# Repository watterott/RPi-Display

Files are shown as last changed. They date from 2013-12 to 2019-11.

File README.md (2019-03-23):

# RPi-Display
2.8" TFT-Display (320x240) with Touchpanel for all Raspberry Pi Models.

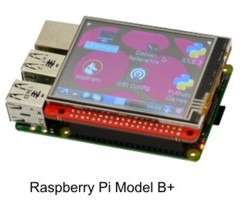
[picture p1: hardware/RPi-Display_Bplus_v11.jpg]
RPi-Display B+

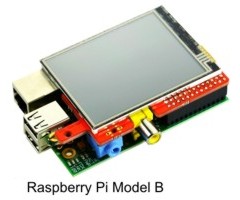
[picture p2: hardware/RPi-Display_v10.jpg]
RPi-Display


* Open-Source and released under the [Creative Commons Attribution Share-Alike License](https://creativecommons.org/licenses/by-sa/4.0/).
* **[Documentation on learn.watterott.com](https://learn.watterott.com)**

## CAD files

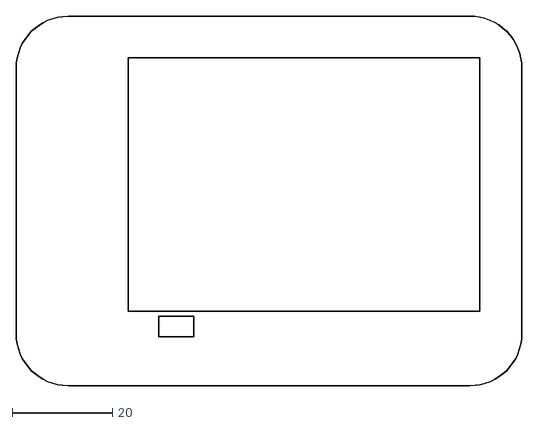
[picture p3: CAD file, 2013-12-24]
hardware/TEK-BERRY.dxf
100.7 x 73.6

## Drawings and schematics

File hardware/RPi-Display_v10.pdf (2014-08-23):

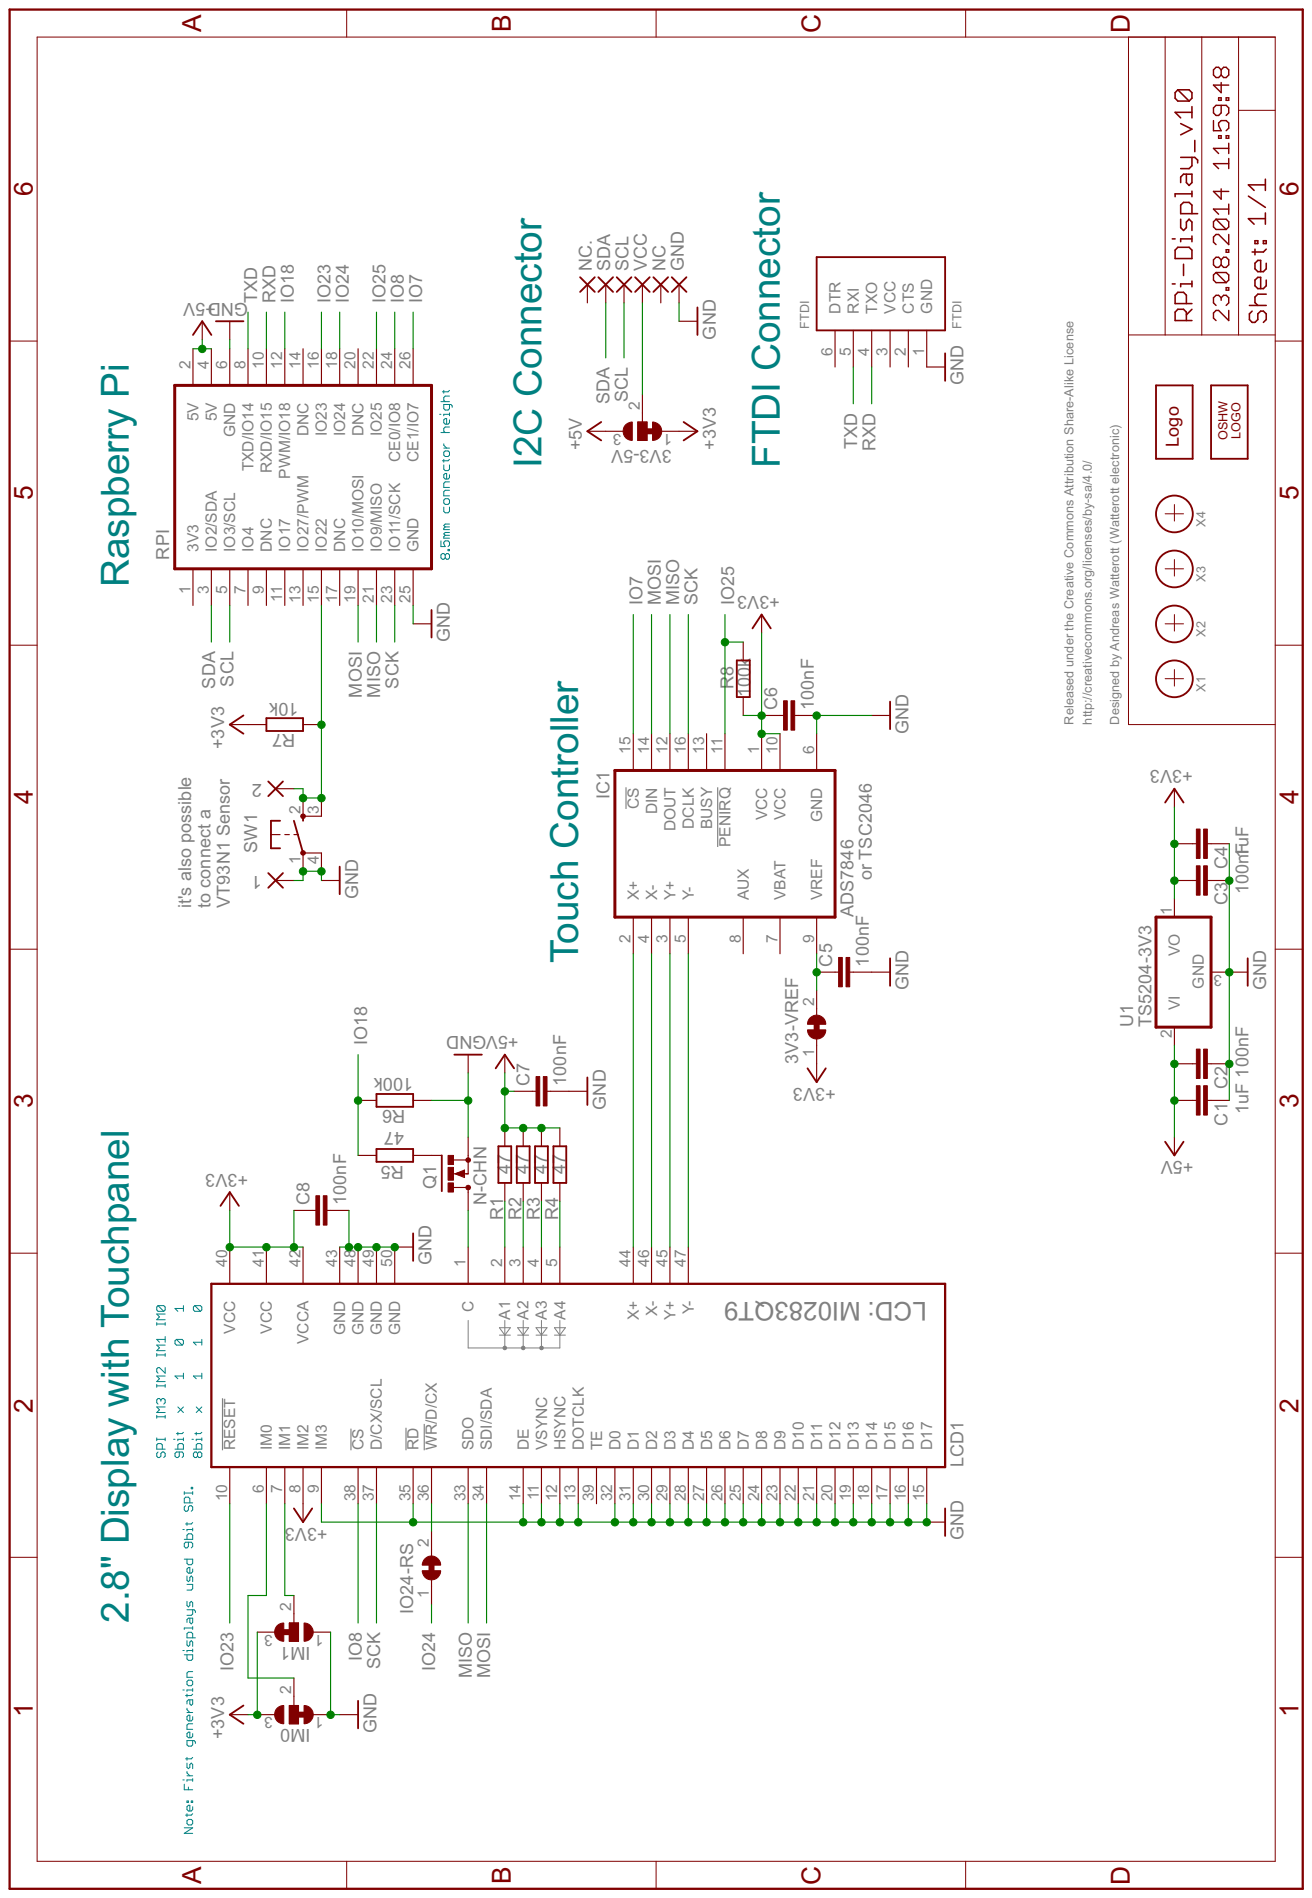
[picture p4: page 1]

GND DNG GND 100nF 100nF TS5204-3V3 1uF 47474747 N-CHN DNG 3V3+ GND 74 100nF GND k001 13V3+ 00nF GND GND GND 3V3+ 3V3+ 3V3+ +3V3 GND k01 +3V3 1uF 100nF 100nF GNDV5+ V5+ 100k V5+ GND GND +3V3 +5V Released under the Creative Commons Attribution Share-Alike License http://creativecommons.org/licenses/by-sa/4.0/ Designed by Andreas Watterott (Watterott electronic) or TSC2046 it's also possible to connect a VT93N1 Sensor RPI 3V3 1 IO2/SDA 3 IO3/SCL 5 5V 2 5V 4 GND 6 IO4 7 DNC 9 TXD/IO14 8 RXD/IO15 10 IO17 11 IO27/PWM 13 IO22 15 PWM/IO18 12 DNC 14 IO23 16 DNC 17 IO10/MOSI 19 IO24 18 DNC 20 IO9/MISO 21 IO11/SCK 23 GND 25 IO25 22 CE0/IO8 24 CE1/IO7 26 C2 C3 GND VI 2 3 VO 1 U1 C1 X1 X2 X3 X4 9TQ3820I M: DCL LCD1 VCC 40 GND 43 VCC 41 X+ 44 SDO 33 RESET 10 D5 27 D4 28 D3 29 D2 30 D1 31 D0 32 RD 35 WR/D/CX 36 D/CX/SCL 37 SDI/SDA 34 A1 2 C 1 A2 3 A3 4 A4 5 VCCA 42 IM0 6 IM1 7 IM2 8 IM3 9 VSYNC 11 HSYNC 12 DOTCLK 13 DE 14 D6 26 D7 25 D8 24 D9 23 D10 22 D11 21 D12 20 D13 19 D14 18 D15 17 D16 16 D17 15 CS 38 TE 39 X- 46 Y+ 45 Y- 47 GND 48 GND 49 GND 50 R1R2R3R4 Q15R X+ 2 Y+ 3 Y- 5 AUX 8 DCLK 16 CS 15 DIN 14 BUSY 13 DOUT 12 PENIRQ 11 X- 4 GND 6 VCC 1 VBAT 7 VCC 10 VREF 9 IC1 ADS7846 C5 6R 2 13V3-VREF C7 2 1 IO24-RS 3 1 2 0 MI 3 1 2 1 MI 7R C4 C8 C6R8 NC. SDA SCL VCC NCGND FTDI FTDI DTR 6 RXI 5 TXO 4 VCC 3 CTS 2 GND 1 SW1 1 23 4 21 3 1 2 V5- 3V3 SDA SDA SCL SCL MISO MISO MISO MOSI MOSI MOSI SCK SCK SCK IO23 IO23 IO24 IO24 IO25 IO25 IO8 IO8 IO7 IO7 IO18 IO18 TXD TXD RXD RXD Logo OSHW LOGO ABCD 1 2 3 4 5 6 ABCD 1 2 3 4 5 6 2.8" Display with Touchpanel Raspberry Pi Touch Controller I2C Connector FTDI Connector

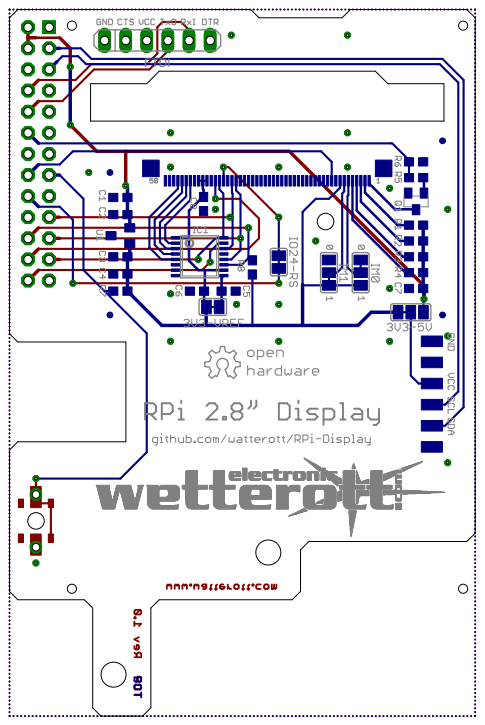
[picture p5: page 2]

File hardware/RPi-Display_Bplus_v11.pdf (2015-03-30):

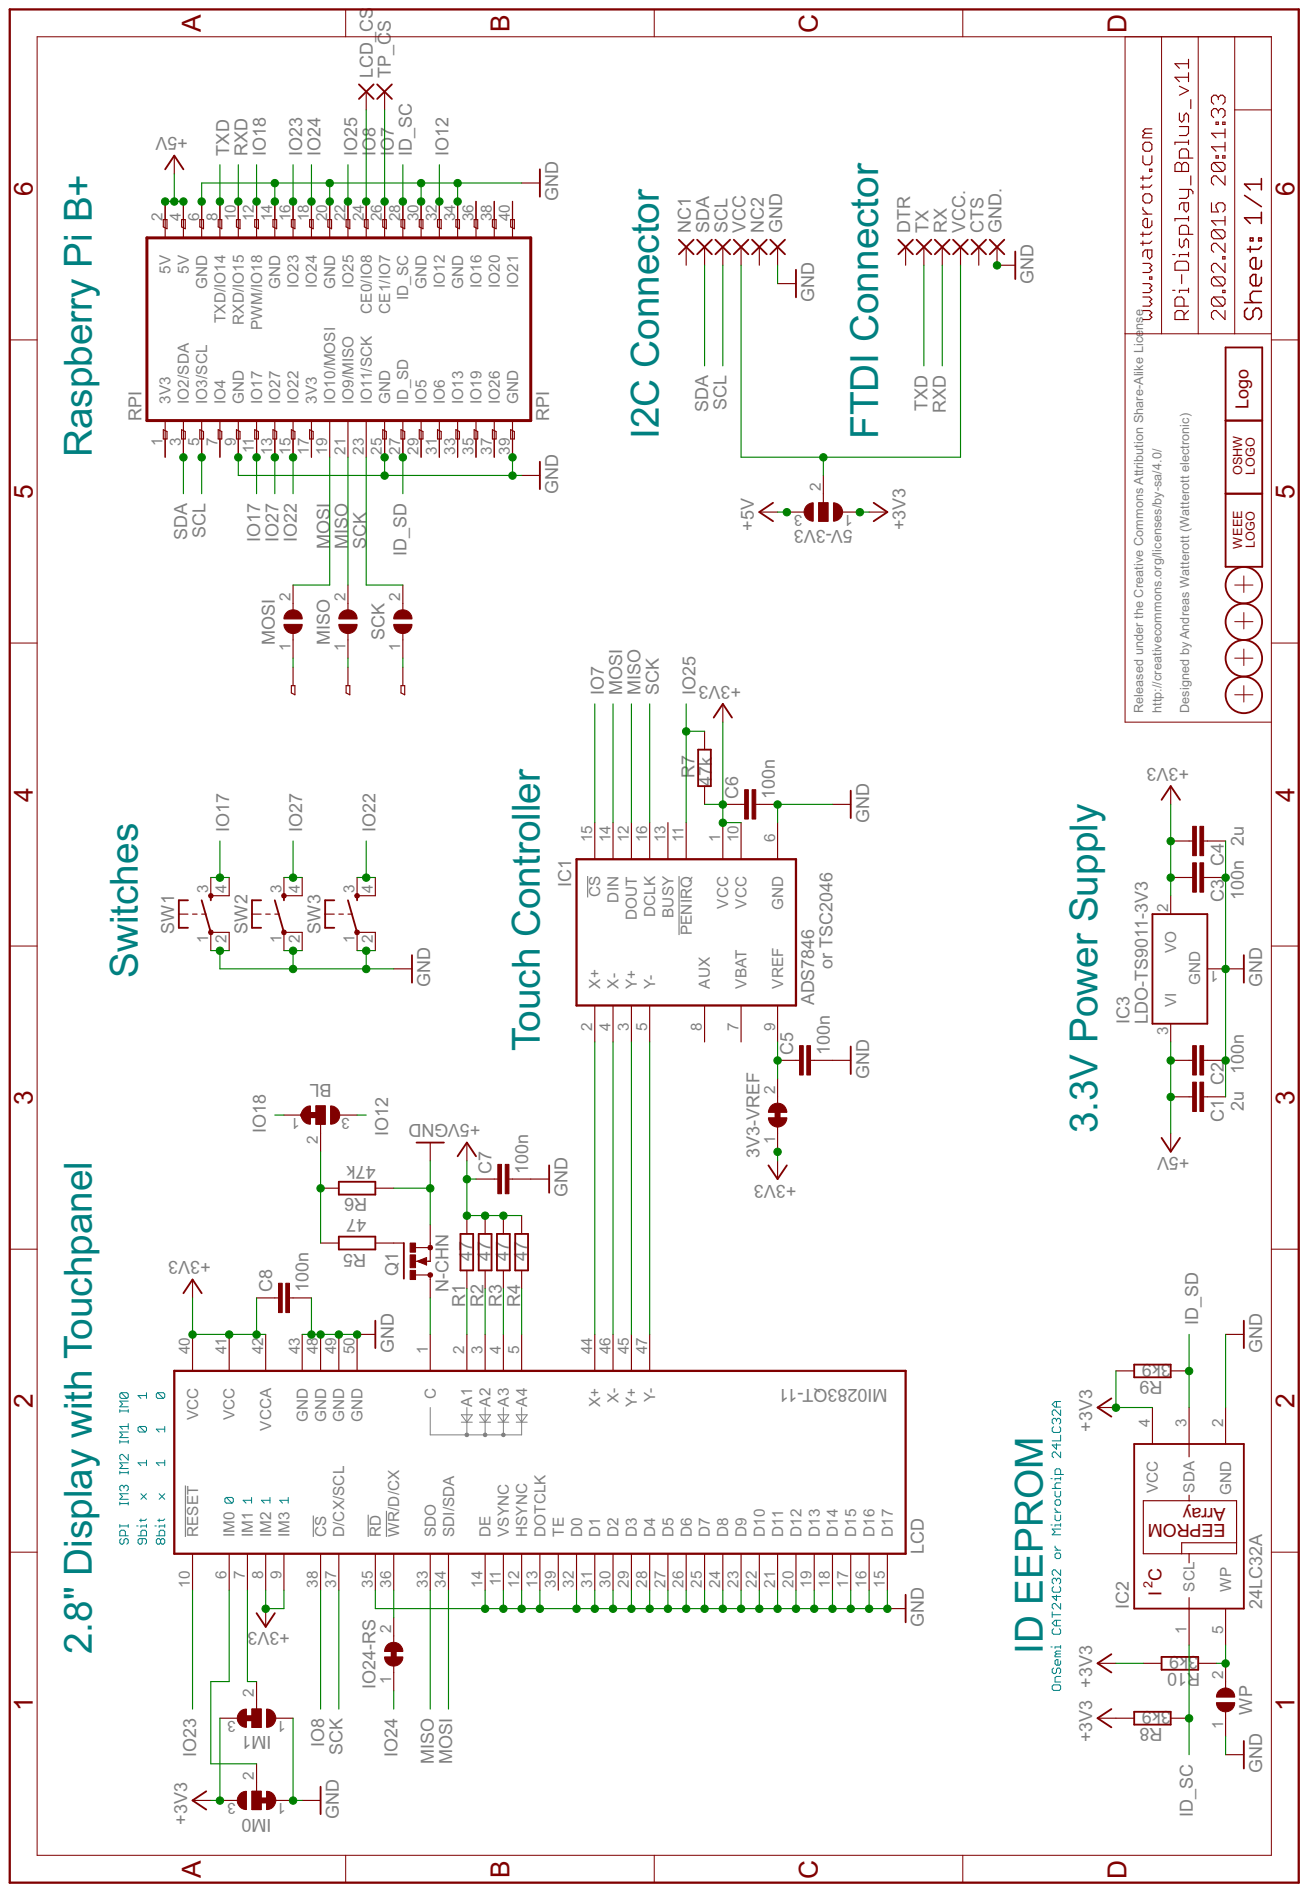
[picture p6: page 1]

LDO-TS9011-3V3 Released under the Creative Commons Attribution Share-Alike License

http://creativecommons.org/licenses/by-sa/4.0/ Designed by Andreas Watterott (Watterott electronic)

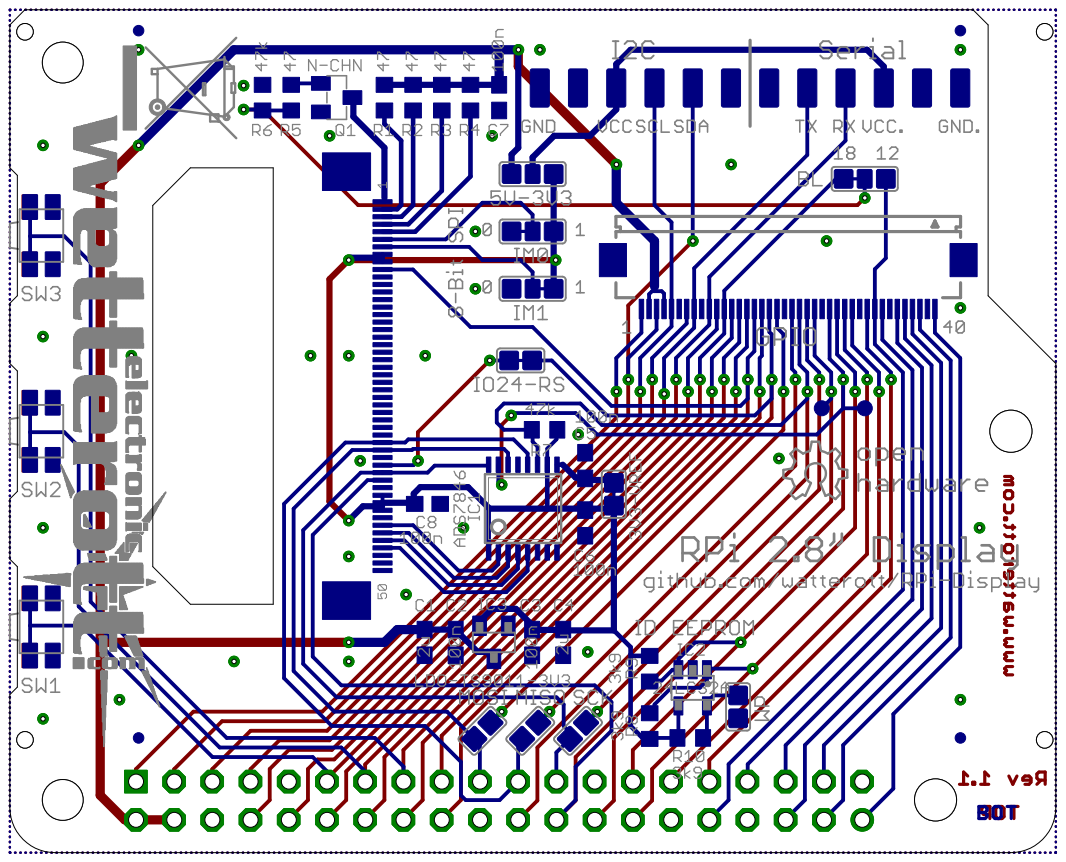
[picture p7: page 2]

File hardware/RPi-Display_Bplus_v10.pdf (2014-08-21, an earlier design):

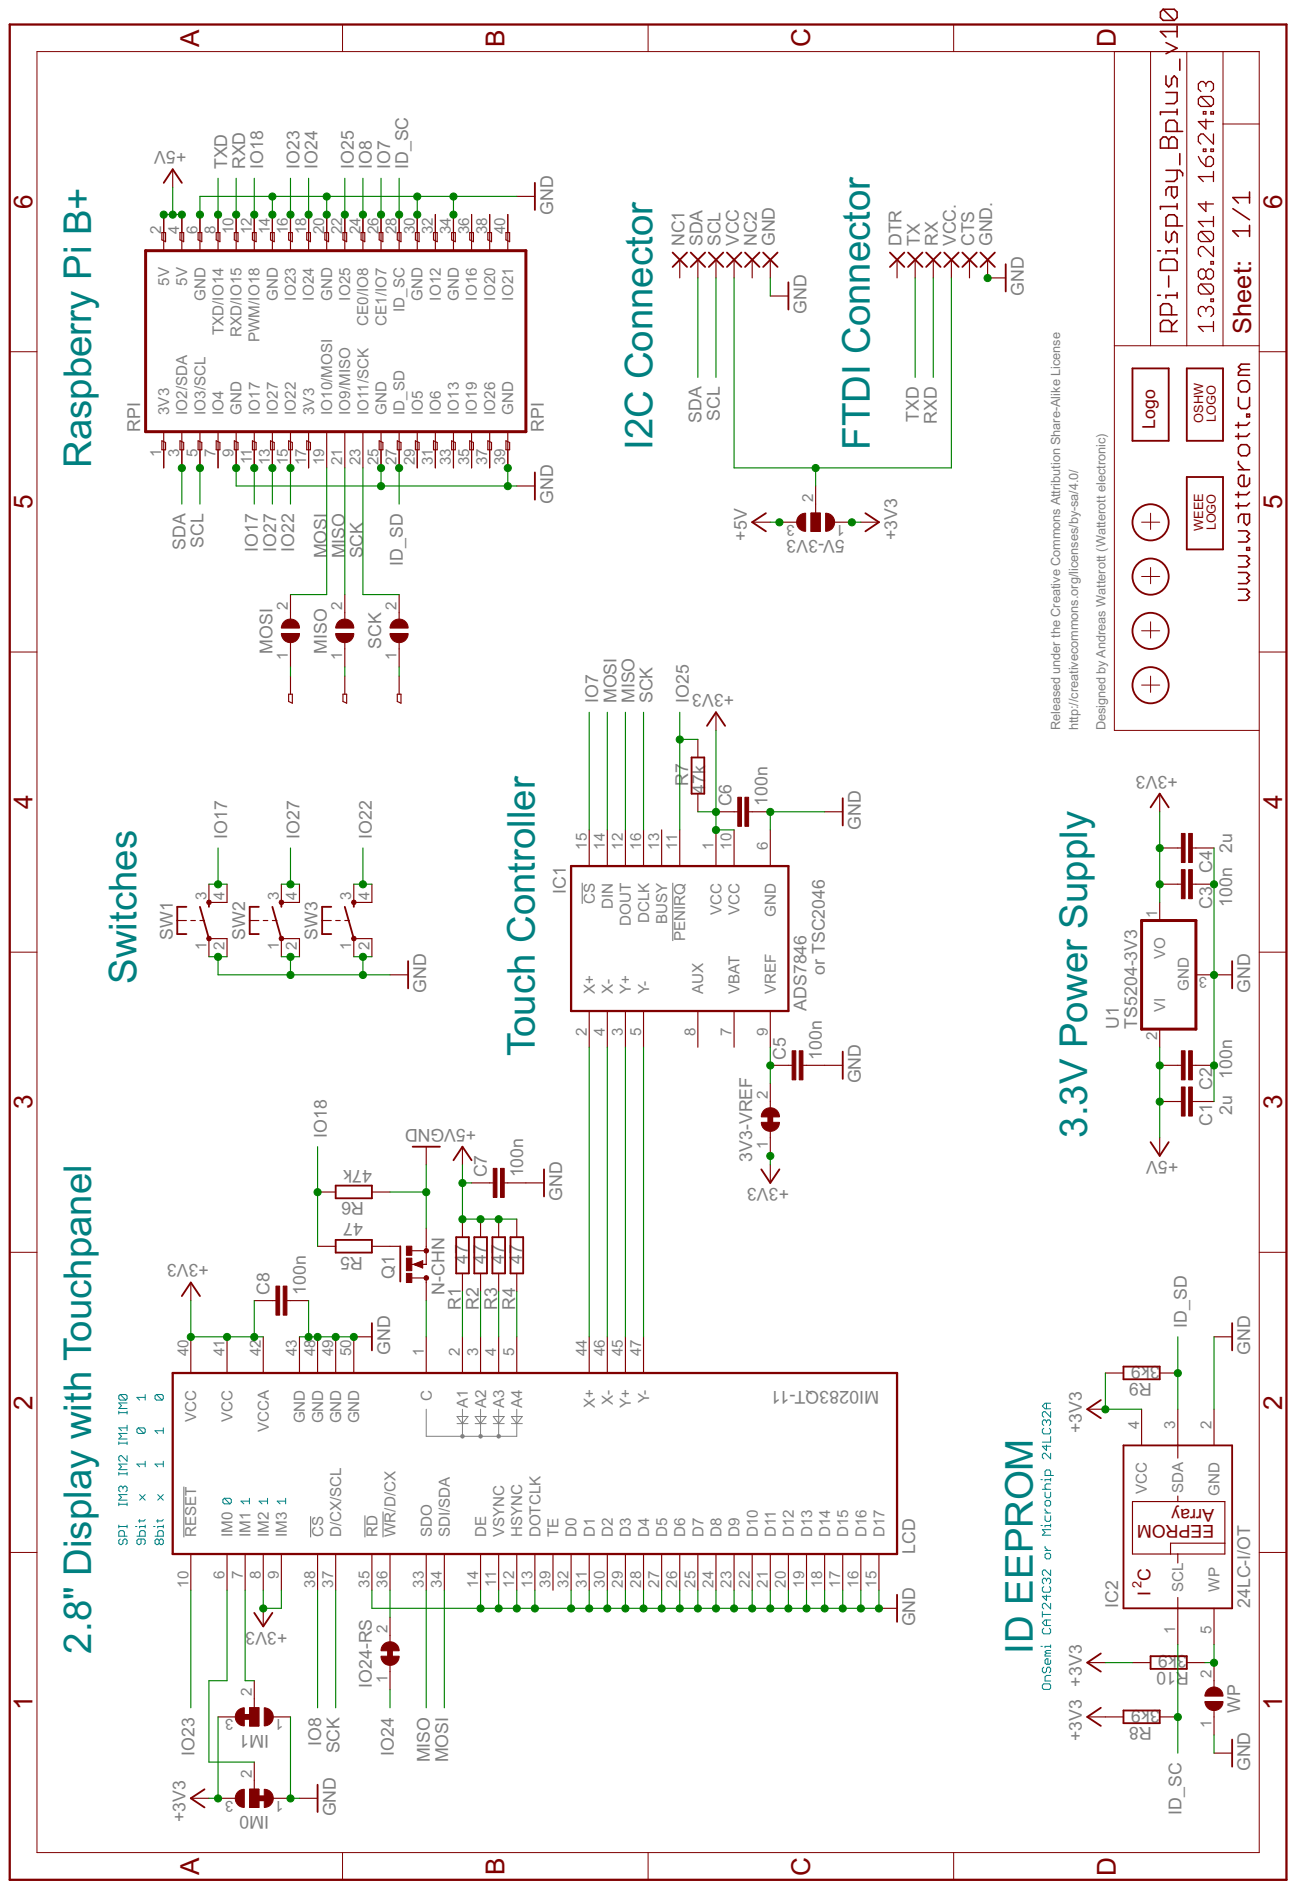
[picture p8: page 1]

Released under the Creative Commons Attribution Share-Alike License

http://creativecommons.org/licenses/by-sa/4.0/ Designed by Andreas Watterott (Watterott electronic)

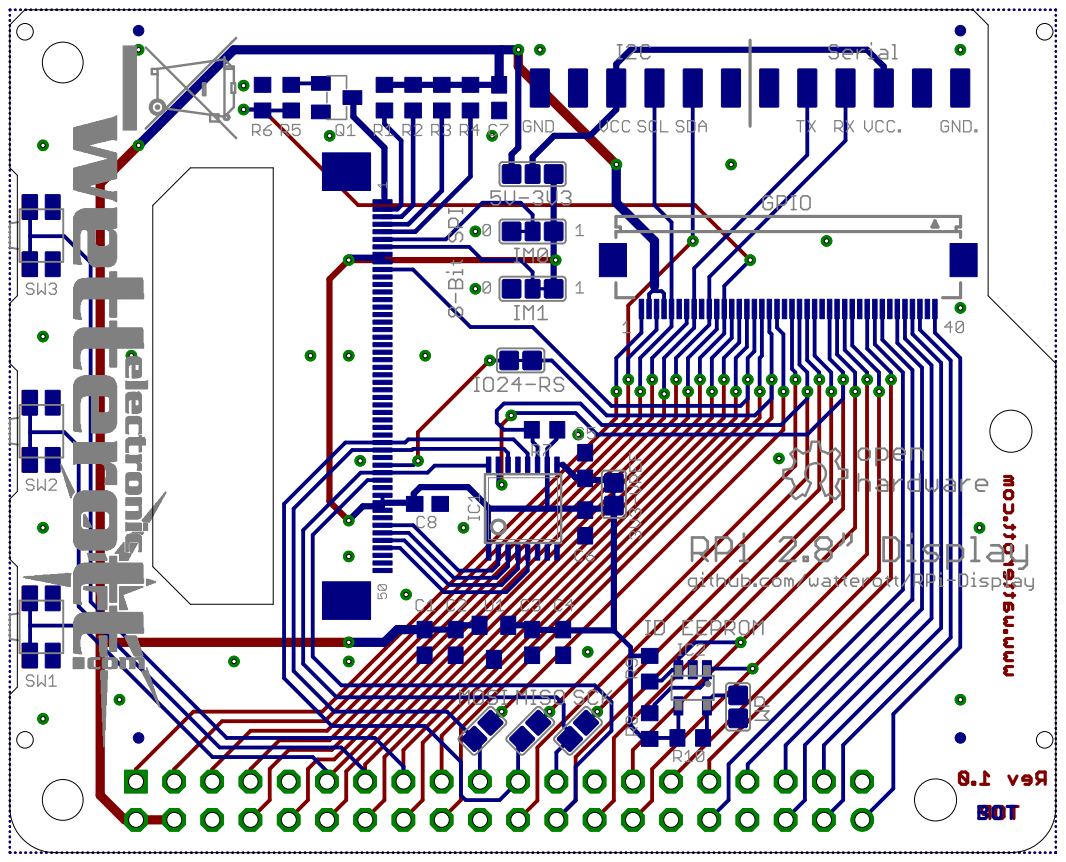
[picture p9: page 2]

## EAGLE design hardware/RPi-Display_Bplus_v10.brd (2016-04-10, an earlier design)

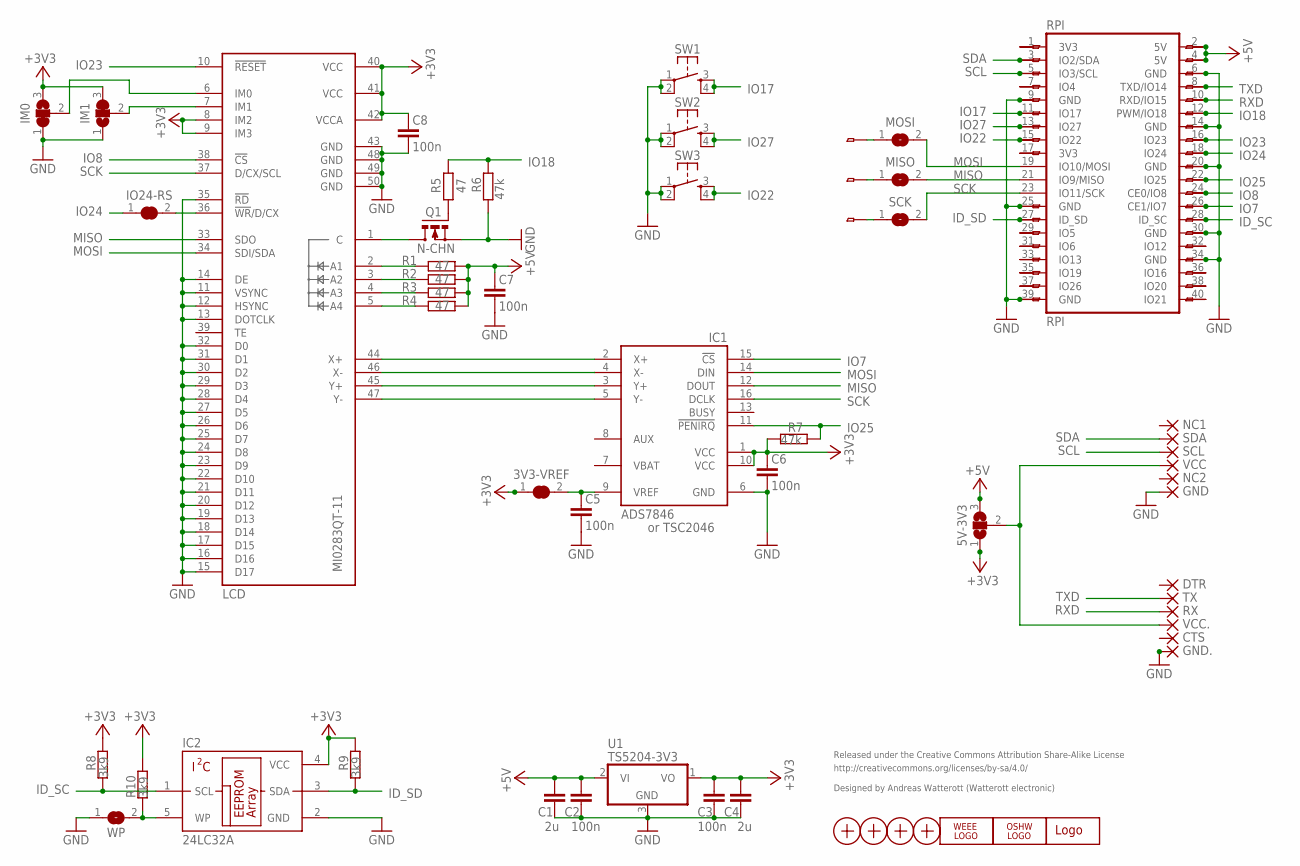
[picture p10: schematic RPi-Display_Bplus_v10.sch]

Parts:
3V3-VREF: JUMPER2-NOCREAM; JUMPER2_NC
5V-3V3: JUMPER3-NOCREAM; JUMPER3_NC
C1, C4: 2u; C0603
C2, C3, C5, C6, C7, C8: 100n; C0603
CTS: PAD-1.27-NC; PAD-1.27X2.54_NC
DTR: PAD-1.27-NC; PAD-1.27X2.54_NC
GND, GND.: PAD-1.27-NC; PAD-1.27X2.54_NC
GPIO: FH12-40S-0.5SH
IC1: ADS7846; SSOP16
IC2: 24LC32A; SOT23-5
IM0, IM1: JUMPER3-NOCREAM; JUMPER3_NC
IO24-RS: JUMPER2-NOCREAM; JUMPER2_NC
LCD: MI0283QT-11; MI0283QT11
LOGO1: OSHW_LOGO_6MILX0150-NT; OSHW_6X150_NOTEXT
LOGO2: WEEE_LOGO; WEEE
MISO: JUMPER2-NOCREAM; JUMPER2_NC
MOSI: JUMPER2-NOCREAM; JUMPER2_NC
NC1, NC2: PAD-1.27-NC; PAD-1.27X2.54_NC
Q1: N-CHN; MICRO3
R1, R2, R3, R4, R5: 47; R0603
R6, R7: 47k; R0603
R8, R9, R10: 3k9; R0603
RPI: RPI; RPI_B+
RX: PAD-1.27-NC; PAD-1.27X2.54_NC
SCK: JUMPER2-NOCREAM; JUMPER2_NC
SCL: PAD-1.27-NC; PAD-1.27X2.54_NC
SDA: PAD-1.27-NC; PAD-1.27X2.54_NC
SW1, SW2, SW3: SWITCH-PTS840P; SW_PTS840P
TX: PAD-1.27-NC; PAD-1.27X2.54_NC
U1: TS5204-3V3; SOT23
U$1: WE-LOGO
VCC, VCC.: PAD-1.27-NC; PAD-1.27X2.54_NC
WP: JUMPER2-NOCREAM; JUMPER2_NC
X1, X2, X3, X4: PASSER

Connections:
+3V3: 3V3-VREF.1, 5V-3V3.1, C3.1, C4.1, C6.1, C8.1, IC1.1 (VCC), IC1.10 (VCC), IC2.4 (VCC), IM0.3, IM1.3, LCD.8 (IM2), LCD.9 (IM3), LCD.40 (VCC), LCD.41 (VCC), LCD.42 (VCCA), R7.2, R8.1, R9.1, R10.1, U1.1 (VO)
+5V: 5V-3V3.3, C1.1, C2.1, C7.1, GPIO.37, GPIO.39, R1.2, R2.2, R3.2, R4.2, RPI.2 (5V), RPI.4 (5V), U1.2 (VI)
C1: LCD.1 (C), Q1.3 (D)
GND: C1.2, C2.2, C3.2, C4.2, C5.2, C6.2, C7.2, C8.2, GND.1, GND..1, GPIO.2, GPIO.7, GPIO.11, GPIO.16, GPIO.21, GPIO.27, GPIO.32, GPIO.35, IC1.6 (GND), IC2.2 (GND), IM0.1, IM1.1, LCD.11 (VSYNC), LCD.12 (HSYNC), LCD.13 (DOTCLK), LCD.14 (DE), LCD.15 (D17), LCD.16 (D16), LCD.17 (D15), LCD.18 (D14), LCD.19 (D13), LCD.20 (D12), LCD.21 (D11), LCD.22 (D10), LCD.23 (D9), LCD.24 (D8), LCD.25 (D7), LCD.26 (D6), LCD.27 (D5), LCD.28 (D4), LCD.29 (D3), LCD.30 (D2), LCD.31 (D1), LCD.32 (D0), LCD.35 (!RD), LCD.43 (GND), LCD.48 (GND), LCD.49 (GND), LCD.50 (GND), Q1.2 (S), R6.2, RPI.6 (GND), RPI.9 (GND), RPI.14 (GND), RPI.20 (GND), RPI.25 (GND), RPI.30 (GND), RPI.34 (GND), RPI.39 (GND), SW1.1, SW1.2 (P1), SW2.1, SW2.2 (P1), SW3.1, SW3.2 (P1), U1.3 (GND), WP.1
ID_SC: GPIO.13, IC2.1 (SCL), R8.2, RPI.28 (ID_SC)
ID_SD: GPIO.14, IC2.3 (SDA), R9.2, RPI.27 (ID_SD)
IM0: IM0.2, LCD.6 (IM0)
IM1: IM1.2, LCD.7 (IM1)
IO7: GPIO.15, IC1.15 (!CS), RPI.26 (CE1/IO7)
IO8: GPIO.17, LCD.38 (!CS), RPI.24 (CE0/IO8)
IO17: GPIO.30, RPI.11 (IO17), SW1.3 (S), SW1.4 (S1)
IO18: GPIO.29, R5.2, R6.1, RPI.12 (PWM/IO18)
IO22: GPIO.26, RPI.15 (IO22), SW3.3 (S), SW3.4 (S1)
IO23: GPIO.25, LCD.10 (!RESET), RPI.16 (IO23)
IO24: GPIO.23, IO24-RS.1, RPI.18 (IO24)
IO25: GPIO.19, IC1.11 (!PENIRQ), R7.1, RPI.22 (IO25)
IO27: GPIO.28, RPI.13 (IO27), SW2.3 (S), SW2.4 (S1)
LEDPWM: Q1.1 (G), R5.1
LED_A1: LCD.2 (A1), R1.1
LED_A2: LCD.3 (A2), R2.1
LED_A3: LCD.4 (A3), R3.1
LED_A4: LCD.5 (A4), R4.1
MISO: IC1.12 (DOUT), LCD.33 (SDO), MISO.2, RPI.21 (IO9/MISO)
MOSI: IC1.14 (DIN), LCD.34 (SDI/SDA), MOSI.2, RPI.19 (IO10/MOSI)
unnamed: IO24-RS.2, LCD.36 (!WR!/D/CX)
unnamed: IC2.5 (WP), R10.2, WP.2
unnamed: GPIO.22, MOSI.1
unnamed: 5V-3V3.2, VCC.1, VCC..1
unnamed: GPIO.20, MISO.1
unnamed: GPIO.18, SCK.1
unnamed: GPIO.40, RPI.1 (3V3)
unnamed: GPIO.34, RPI.7 (IO4)
unnamed: GPIO.24, RPI.17 (3V3)
unnamed: GPIO.12, RPI.29 (IO5)
unnamed: GPIO.10, RPI.31 (IO6)
unnamed: GPIO.8, RPI.33 (IO13)
unnamed: GPIO.6, RPI.35 (IO19)
unnamed: GPIO.4, RPI.37 (IO26)
unnamed: GPIO.9, RPI.32 (IO12)
unnamed: GPIO.5, RPI.36 (IO16)
unnamed: GPIO.3, RPI.38 (IO20)
unnamed: GPIO.1, RPI.40 (IO21)
RXD: GPIO.31, RPI.10 (RXD/IO15), RX.1
SCK: IC1.16 (DCLK), LCD.37 (D/CX/SCL), RPI.23 (IO11/SCK), SCK.2
SCL: GPIO.36, RPI.5 (IO3/SCL), SCL.1
SDA: GPIO.38, RPI.3 (IO2/SDA), SDA.1
TXD: GPIO.33, RPI.8 (TXD/IO14), TX.1
VREF: 3V3-VREF.2, C5.1, IC1.9 (VREF)
X+: IC1.2 (X+), LCD.44 (X+)
X-: IC1.4 (X-), LCD.46 (X-)
Y+: IC1.3 (Y+), LCD.45 (Y+)
Y-: IC1.5 (Y-), LCD.47 (Y-)

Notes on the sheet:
Released under the Creative Commons Attribution Share-Alike License
http://creativecommons.org/licenses/by-sa/4.0/
Designed by Andreas Watterott (Watterott electronic)
or TSC2046

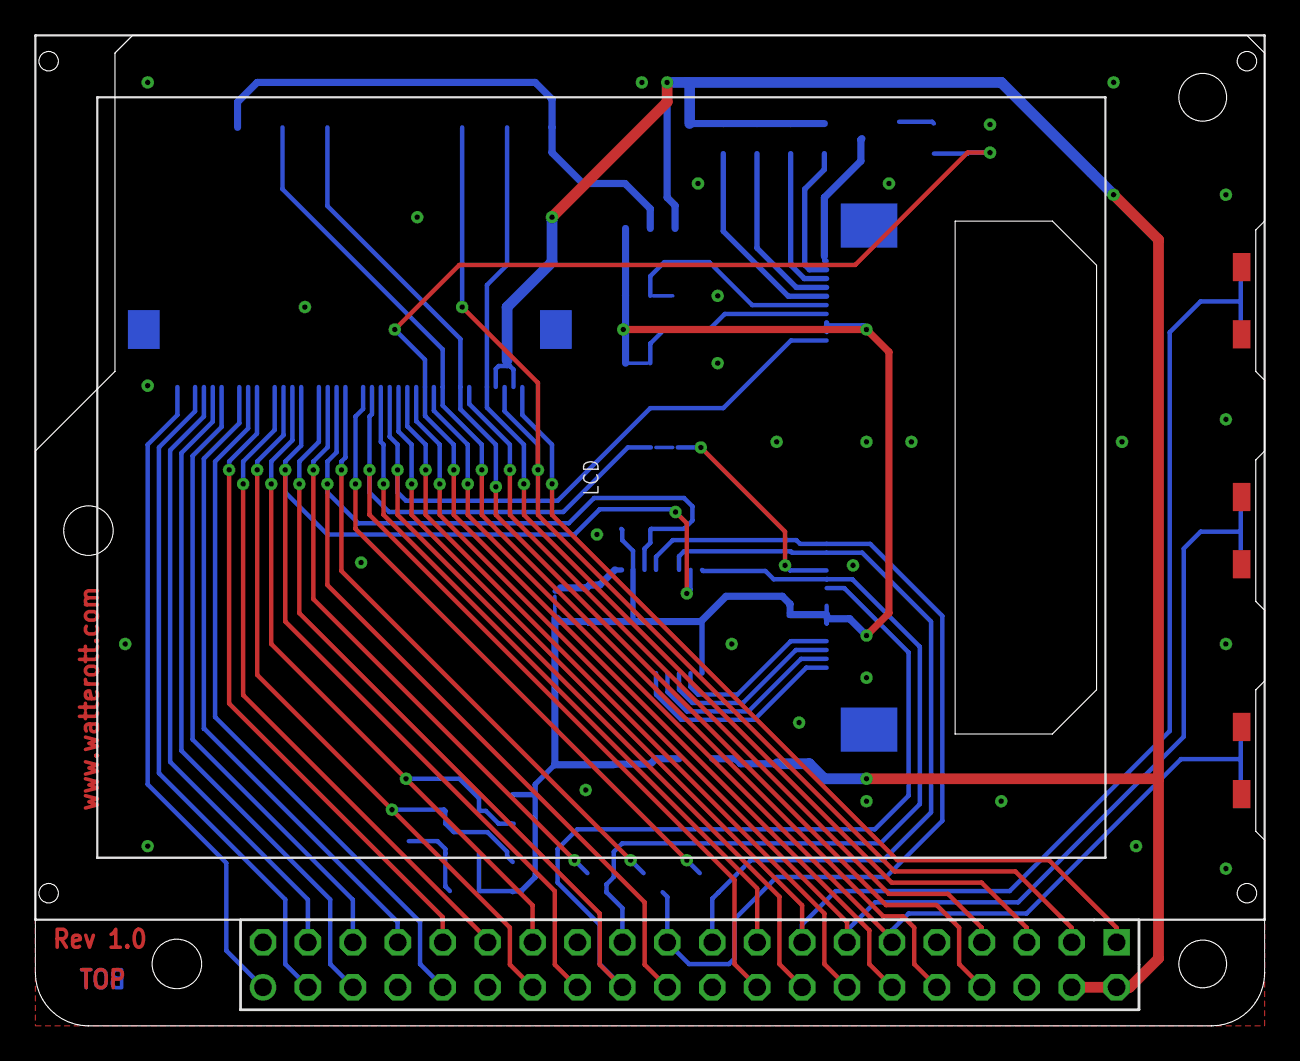
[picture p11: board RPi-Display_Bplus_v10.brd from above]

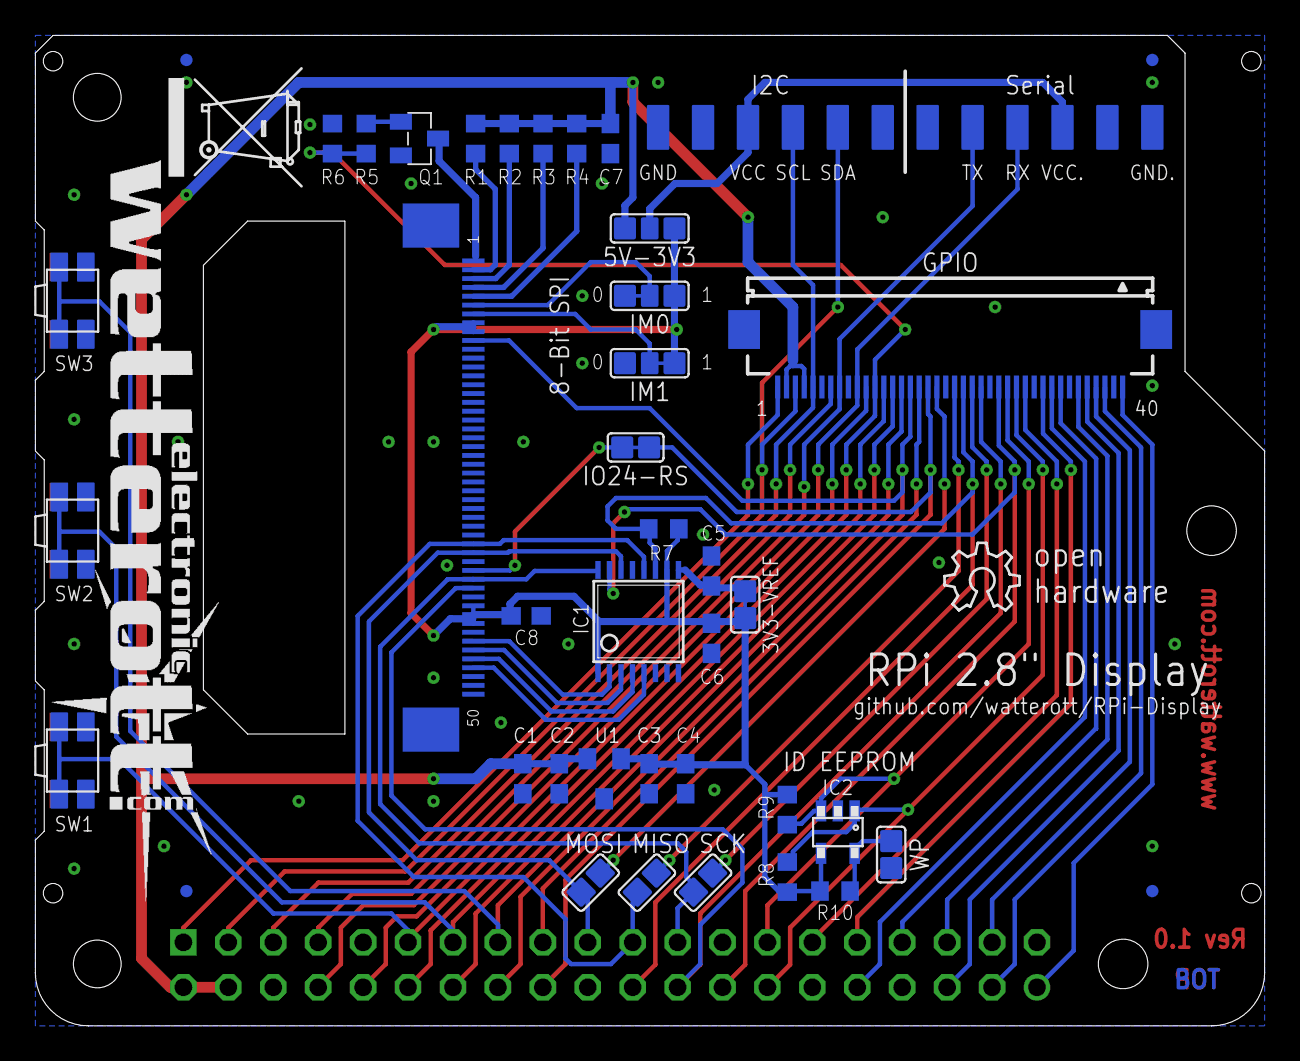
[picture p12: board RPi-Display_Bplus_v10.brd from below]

Board: 2 copper layers, 69.5 x 56.0 mm, 56 parts (54 on the bottom side), 52 nets.

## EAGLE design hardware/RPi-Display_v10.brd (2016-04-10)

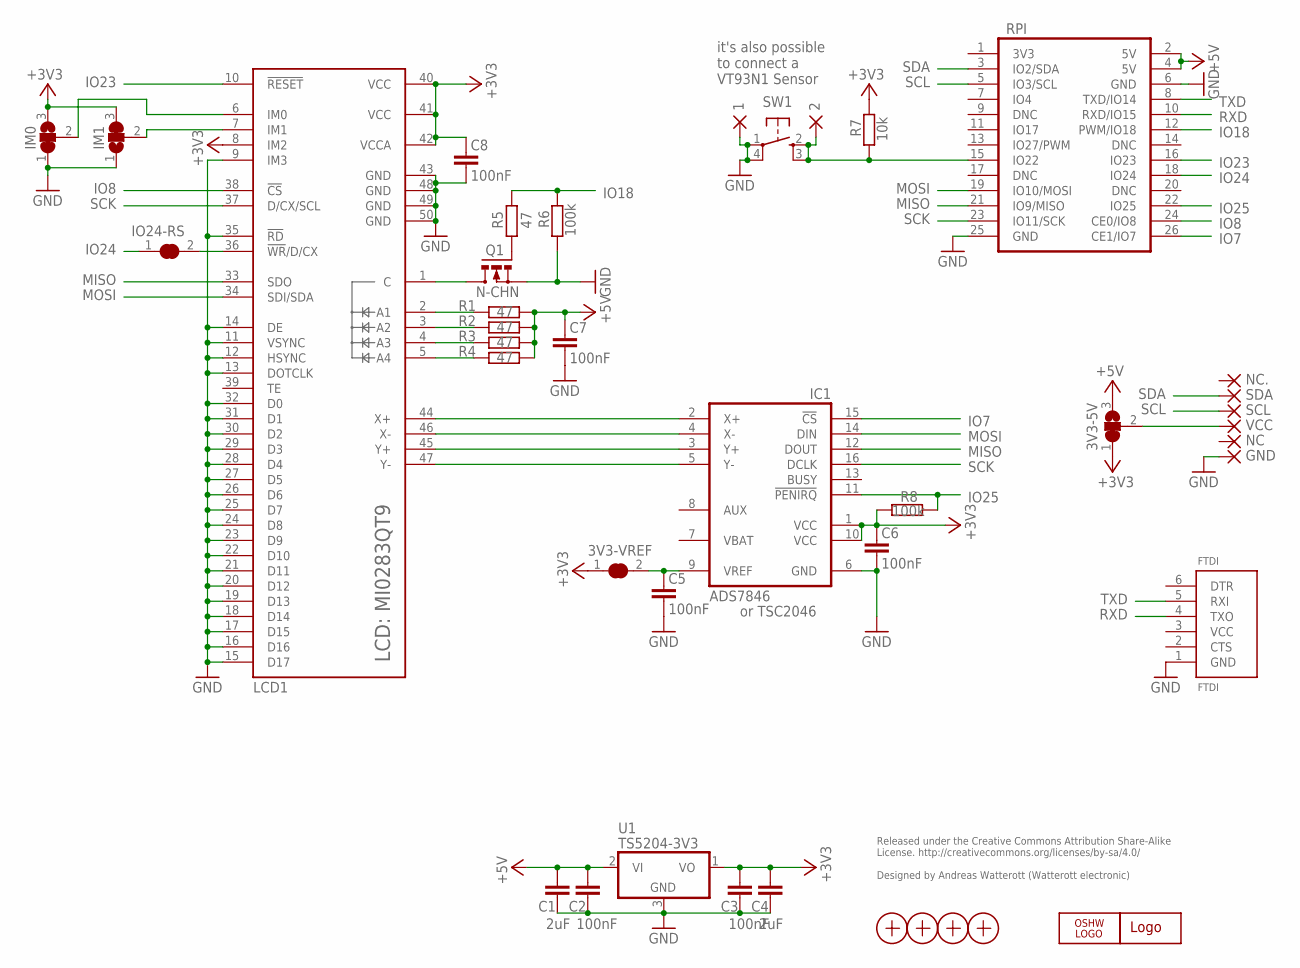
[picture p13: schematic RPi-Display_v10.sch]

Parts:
1, 2: WIREPADSMD1,27-254; SMD1,27-2,54
3V3-5V: SJ2W; SJ_2
3V3-VREF: SJ
C1, C4: 2uF; C0603
C2, C3, C5, C6, C7, C8: 100nF; C0603
FTDI: FTDI
GND: WIREPADSMD1,27-254; SMD1,27-2,54
IC1: ADS7846; SSOP16
IM0, IM1: SJ2W; SJ_2
IO24-RS: SJ
LCD1: MI0283QT9
LOGO1: OSHW_LOGO_6MILX0150-NT; OSHW_6X150_NOTEXT
NC, NC.: WIREPADSMD1,27-254; SMD1,27-2,54
Q1: N-CHN; MICRO3
R1, R2, R3, R4, R5: 47; R0603
R6, R8: 100k; R0603
R7: 10k; R0603
RPI: RPI
SCL: WIREPADSMD1,27-254; SMD1,27-2,54
SDA: WIREPADSMD1,27-254; SMD1,27-2,54
SW1: SW4S; SW_SMD4
U1: TS5204-3V3; SOT23
U$1: WE-LOGO
VCC: WIREPADSMD1,27-254; SMD1,27-2,54
X1, X2, X3, X4: PASSER

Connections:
+3V3: 3V3-5V.1, 3V3-VREF.1, C3.1, C4.1, C6.1, C8.1, IC1.1 (VCC), IC1.10 (VCC), IM0.3, IM1.3, LCD1.8 (IM2), LCD1.40 (VCC), LCD1.41 (VCC), LCD1.42 (VCCA), R7.1, R8.2, U1.1 (VO)
+5V: 3V3-5V.3, C1.1, C2.1, C7.1, R1.2, R2.2, R3.2, R4.2, RPI.2 (5V), RPI.4 (5V), U1.2 (VI)
C1: LCD1.1 (C), Q1.3 (D)
GND: 1.1, C1.2, C2.2, C3.2, C4.2, C5.2, C6.2, C7.2, C8.2, FTDI.1 (GND), GND.1, IC1.6 (GND), IM0.1, IM1.1, LCD1.9 (IM3), LCD1.11 (VSYNC), LCD1.12 (HSYNC), LCD1.13 (DOTCLK), LCD1.14 (DE), LCD1.15 (D17), LCD1.16 (D16), LCD1.17 (D15), LCD1.18 (D14), LCD1.19 (D13), LCD1.20 (D12), LCD1.21 (D11), LCD1.22 (D10), LCD1.23 (D9), LCD1.24 (D8), LCD1.25 (D7), LCD1.26 (D6), LCD1.27 (D5), LCD1.28 (D4), LCD1.29 (D3), LCD1.30 (D2), LCD1.31 (D1), LCD1.32 (D0), LCD1.35 (!RD), LCD1.43 (GND), LCD1.48 (GND), LCD1.49 (GND), LCD1.50 (GND), Q1.2 (S), R6.2, RPI.6 (GND), RPI.25 (GND), SW1.1, SW1.4 (P1), U1.3 (GND)
IM0: IM0.2, LCD1.6 (IM0)
IM1: IM1.2, LCD1.7 (IM1)
IO7: IC1.15 (!CS), RPI.26 (CE1/IO7)
IO8: LCD1.38 (!CS), RPI.24 (CE0/IO8)
IO18: R5.2, R6.1, RPI.12 (PWM/IO18)
IO22: 2.1, R7.2, RPI.15 (IO22), SW1.2 (S), SW1.3 (S1)
IO23: LCD1.10 (!RESET), RPI.16 (IO23)
IO24: IO24-RS.1, RPI.18 (IO24)
IO25: IC1.11 (!PENIRQ), R8.1, RPI.22 (IO25)
LEDPWM: Q1.1 (G), R5.1
LED_A1: LCD1.2 (A1), R1.1
LED_A2: LCD1.3 (A2), R2.1
LED_A3: LCD1.4 (A3), R3.1
LED_A4: LCD1.5 (A4), R4.1
MISO: IC1.12 (DOUT), LCD1.33 (SDO), RPI.21 (IO9/MISO)
MOSI: IC1.14 (DIN), LCD1.34 (SDI/SDA), RPI.19 (IO10/MOSI)
unnamed: IO24-RS.2, LCD1.36 (!WR!/D/CX)
unnamed: 3V3-5V.2, VCC.1
RXD: FTDI.4 (TXO), RPI.10 (RXD/IO15)
SCK: IC1.16 (DCLK), LCD1.37 (D/CX/SCL), RPI.23 (IO11/SCK)
SCL: RPI.5 (IO3/SCL), SCL.1
SDA: RPI.3 (IO2/SDA), SDA.1
TXD: FTDI.5 (RXI), RPI.8 (TXD/IO14)
VREF: 3V3-VREF.2, C5.1, IC1.9 (VREF)
X+: IC1.2 (X+), LCD1.44 (X+)
X-: IC1.4 (X-), LCD1.46 (X-)
Y+: IC1.3 (Y+), LCD1.45 (Y+)
Y-: IC1.5 (Y-), LCD1.47 (Y-)

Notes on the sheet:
Released under the Creative Commons Attribution Share-Alike License. http://creativecommons.org/licenses/by-sa/4.0/ Designed by Andreas Watterott (Watterott electronic)
or TSC2046
it's also possible to connect a VT93N1 Sensor

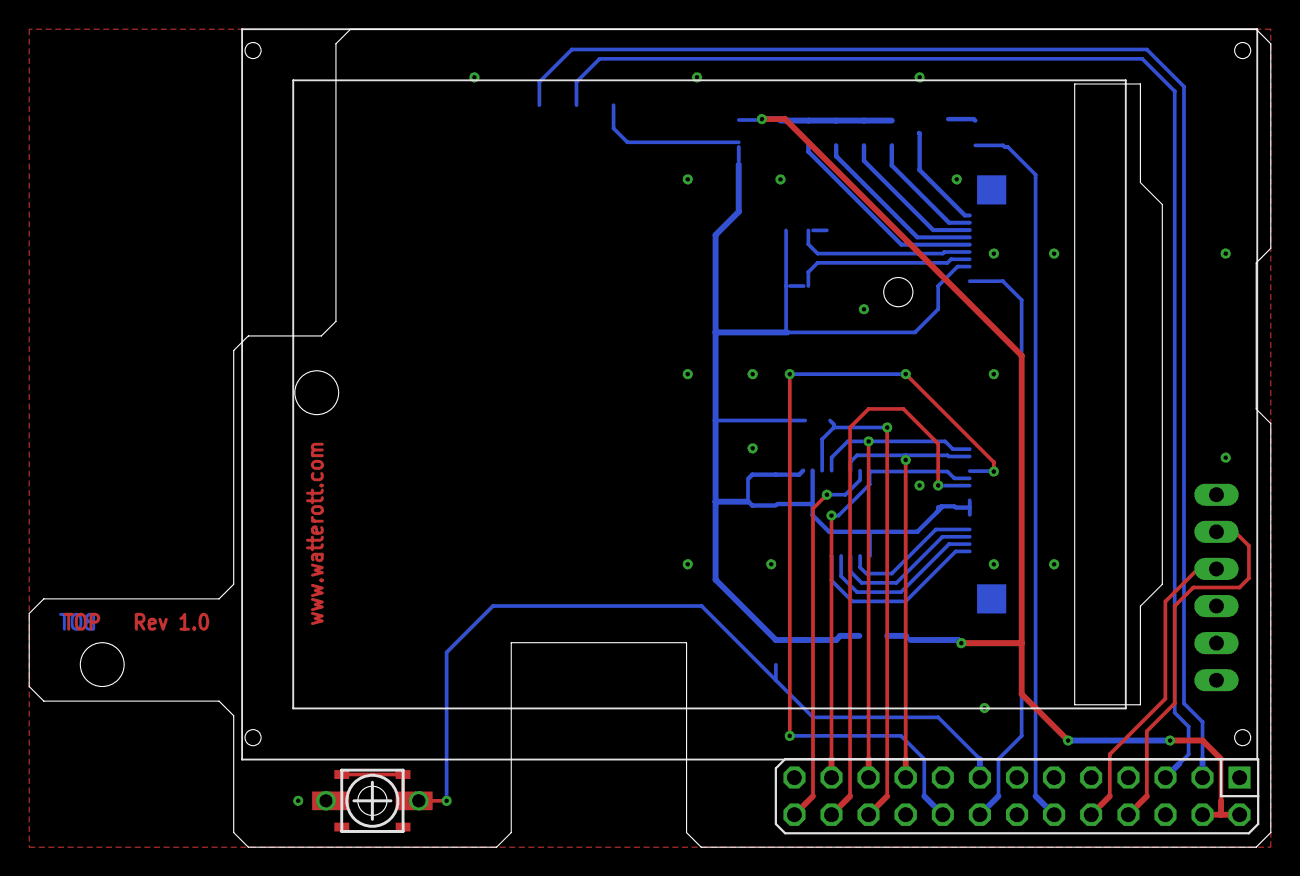
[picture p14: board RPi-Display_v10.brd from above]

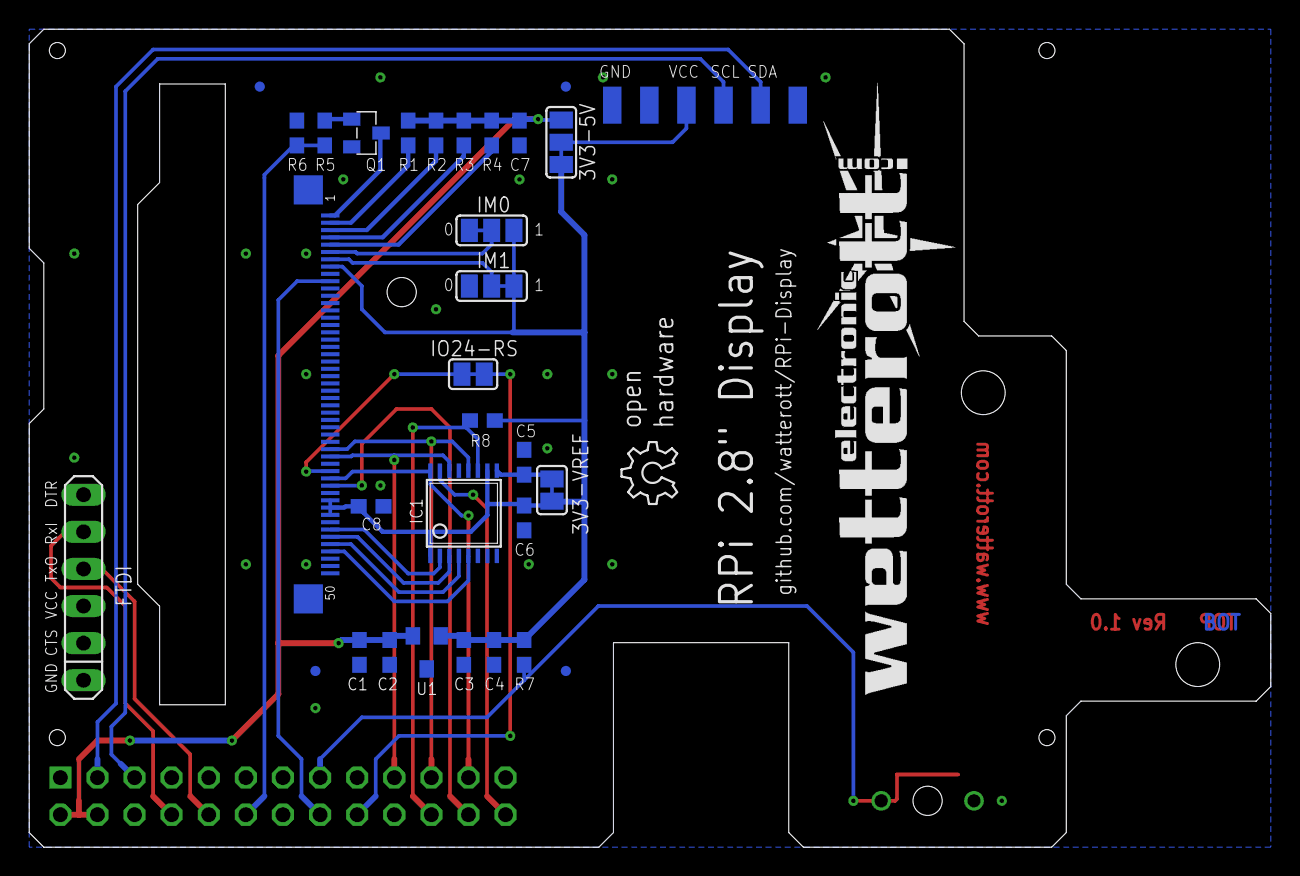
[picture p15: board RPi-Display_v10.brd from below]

Board: 2 copper layers, 85.0 x 56.0 mm, 42 parts (37 on the bottom side), 32 nets.

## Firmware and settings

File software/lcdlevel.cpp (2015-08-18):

//============================================================================
// Name        : lcdlevel.cpp
// Author      : Friedemann Wolpert
// Version     : 1.0.0
// Copyright   : All Rights Reversed, based on wiringPi / Pi-blaster
// Description : Backlight control for Watterott RPi Display (Soft PWM Pin 18)
// Building :
//   * Install WiringPi: http://wiringpi.com/download-and-install/
//   * Compile: cc -o lcdlevel lcdlevel.cpp -lwiringPi -lpthread
//   * Set execution right: chmod +x lcdlevel
//============================================================================

//#include <iostream>
#include <stdio.h>
#include <stdlib.h>
#include <sys/types.h>
#include <sys/stat.h>
#include <getopt.h>
#include <unistd.h>

using namespace std;

#include "wiringPi.h"
#include "softPwm.h"

#define DEVFILE "/dev/lcdlevel"
//#define DEVFILE "/home/pi/lcd"

static char VERSION[] = "1.0.0";
static int lcdlevel = 100;

static void parseDevFileLoop(void);


void parseargs(int argc, char **argv)
{
  int index=0;
  int c;

  static struct option longopts[] =
  {
    {"help", no_argument, 0, 'h'},
    {"level", required_argument, 0, 'l'},
    {"version", no_argument, 0, 'v'},
    {0, 0, 0, 0}
  };

  while((c = getopt_long(argc, argv, "hl:v", longopts, &index )) != -1)
  {
    switch(c)
    {
      case 0:
        break;

      case 'h':
        fprintf(stderr, "%s version %s\n", argv[0], VERSION);
        fprintf(stderr, "Usage: %s [-hlv]\n"
                        "-h (--help)    - this information\n"
                        "-l (--level)   - set LCD Brightness 0 - 100%%\n"
                        "-v (--version) - version information\n"
                        "Example:\n"
                        "Usage : sudo ./lcdlevel -l 100\n"
                        "Update: echo \"99\" > /dev/lcdlevel\n"
                , argv[0]);
        exit(-1);

      case 'l':
        lcdlevel = atoi(optarg);
        break;

      case 'v':
        fprintf(stderr, "%s version %s\n", argv[0], VERSION);
        exit(-1);

      case '?':
        /* getopt_long already reported error? */
        exit(-1);

      default:
        exit(-1);
    }
  }
  }


int main(int argc, char **argv)
{
  // "sudo ./lcdlevel -l 0...100"
  parseargs(argc, argv);

  unlink(DEVFILE);

  if(mkfifo(DEVFILE, 0666) < 0)
  {
    printf("LCDLevel: Failed to open: %s: %m\n", DEVFILE);
    exit(0);
  }

  if(chmod(DEVFILE, 0666) < 0)
  {
    printf("LCDLevel: Failed to set permissions on: %s: %m\n", DEVFILE);
    exit(0);
  }

  printf("Setup LCD GPIO\n");
  wiringPiSetupGpio();

  if(lcdlevel>100) lcdlevel=100;
  if(lcdlevel<0)   lcdlevel=0;

  printf("CreateSoftPWM: %i\n", lcdlevel);

  softPwmCreate(18, lcdlevel, 100);

  // Read Brightness from file
  parseDevFileLoop();

  return 0;
}


// echo "20" > /dev/lcdlevel
static void parseDevFileLoop(void)
{
  FILE *fp;

  if((fp = fopen(DEVFILE, "r+")) == NULL)
  {
    printf("lcdlevel: Failed to open %s: %m\nCannot update display brightness\n", DEVFILE);
  }

  char *lineptr = NULL;
  size_t linelen;

  for(;;)
  {
    int n, value;

    if((n = getline(&lineptr, &linelen, fp)) < 0)
    {
      continue;
    }

    if (n > 4 )
    {
      fprintf(stderr, "Bad input: %s", lineptr);
    }

    value = atoi(lineptr);

    if ( (value >= 0)  && (value <= 100 ))
    {
      lcdlevel=value;
      softPwmWrite(18, lcdlevel);
    }
  }
}

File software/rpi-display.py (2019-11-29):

#!/usr/bin/python

import pygame
from pygame.locals import *
import os
from time import sleep

# set display device
#os.putenv('SDL_VIDEODRIVER', 'fbcon')
os.putenv('SDL_FBDEV', '/dev/fb1')

# set mouse device
#os.putenv('SDL_MOUSEDRV', 'TSLIB')
#os.putenv('SDL_MOUSEDEV', '/dev/input/touchscreen')
#os.putenv('SDL_MOUSEDEV', 'ADS7846 Touchscreen')

# init pygame
pygame.init()
lcd = pygame.display.set_mode((320, 240))
lcd.fill((80,80,80))
pygame.mouse.set_visible(True)
pygame.display.update()

# show input devices
#from evdev import InputDevice, list_devices
#devices = map(InputDevice, list_devices())
#for dev in devices:
#    print dev.name

# show mouse data
try:
    while True:
        for event in pygame.event.get():
            if(event.type is MOUSEBUTTONDOWN):
                pos = pygame.mouse.get_pos()
                print(pos)
            elif(event.type is MOUSEBUTTONUP):
                pos = pygame.mouse.get_pos()
                print(pos)
        sleep(0.1)
except KeyboardInterrupt:
    pass

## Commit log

2013-12-24 added schematics and layout
    [RPi-Display_v10.brd, RPi-Display_v10.sch, TEK-BERRY.dxf]
2014-03-10 updated license infos
    [RPi-Display_v10.sch]
2014-08-15 updated schematic and layout files
    [RPi-Display_v10.brd, RPi-Display_v10.sch]
2014-08-21 updated layout and schematics
    [RPi-Display_Bplus_v10.brd, RPi-Display_Bplus_v10.sch]
2014-11-06 cleaned up schematics and layout
    [RPi-Display_Bplus_v10.brd, RPi-Display_Bplus_v10.sch, RPi-Display_v10.brd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]
2014-11-07 added GPIO-Adapter
    [GPIO-Adapter_v10.brd, GPIO-Adapter_v10.sch]
2014-12-10 updated schematics
    [RPi-Display_Bplus_v10.brd, RPi-Display_Bplus_v10.sch]
2015-01-22 updated layout
    [RPi-Display_Bplus_v10.brd, RPi-Display_v10.brd]
2015-02-08 updated docu for Device Tree enabled Kernel
2015-02-13 Change /dev/input/eventX device char to touchscreen
    Create a new udrev-rule for making a symlink from the current touchscreen device char /dev/input/eventX to /dev/input/touchscreen
2015-02-13 Updated calibration instruction
    ts_calibrate: changed parameter /dev/input/eventX to /dev/input/touchscreen
2015-03-16 added check for device tree
2015-03-30 added rev 1.1 layout and schematics
    [RPi-Display_Bplus_v11.brd, RPi-Display_Bplus_v11.sch]
2015-08-21 changed path structure
    [GPIO-Adapter_v10.brd, GPIO-Adapter_v10.sch, RPi-Display_Bplus_v10.brd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]
2015-11-26 updated docu and schematics
    [GPIO-Adapter_v10.brd, GPIO-Adapter_v10.sch, RPi-Display_Bplus_v11.brd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]
2017-03-28 updated calibration script
2017-12-28 add backlight pin override
    add backlight pin override
2018-09-27 added GPIO-Adapter rev 1.1
    [GPIO-Adapter_v11.brd, GPIO-Adapter_v11.sch]
2018-12-13 moved to FFC-Extender repo
    [GPIO-Adapter_v10.brd, GPIO-Adapter_v10.sch, GPIO-Adapter_v11.brd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]
